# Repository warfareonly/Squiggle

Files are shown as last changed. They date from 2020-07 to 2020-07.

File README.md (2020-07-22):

This is a fork of ibnuda's Squiggle keyboard, with minor (aesthetic) changes
for myself!

# Squiggle Keyboard

It's a keyboard family which based on my circumstances, preferences, and
observed usages.

Requirements:

- 5 columns per hand.
  My right pinky is almost useless.
- At most 3 keys for each side's thumb row.
  My right thumb key is almost useless.
- No numrow.
  It's harder and more cumbersome to use than a numpad on a layer.
- Split.
  Typing on single flat keyboard hurts my arms in a lot of use cases.
- Symmetric.
  Personal preferences.

This family keyboard repo will not have any of the following features:

- OLED Screen: useless.
- LEDs: useless for me and hurt my eyes.
- Rotary Encoder: useless for me.
- Hotswap: I need a commitment.
- Case for `Low Profile`: defeating the whole purpose of ***LOW*** profile.

## Screenshot

### Standard

- MX and Alps style switches.
- 34 Keys.
- 4x2u thumb keys.
- 2 Promicros.
- TRRS/TRS cable.

standard version

### Low Profile

- Dongguan Kaihua Electronics Co., Ltd (originally named Longhua Electronics)'s
  Choc style switches.
- 34 Keys.
- 4x2u thumb keys.
- 2 Promicros.
- TRRS/TRS cable.

low profile

### 36 Keys

- MX and Alps style switches.
- 36 Keys.
- 4x2u+2x1.25u thumb keys.
- 2 Promicros.
- TRRS/TRS cable.

36 keys

### Minimalist

- MX and Alps style switches.
- 34 Keys.
- 4x2u thumb keys.
- 1 Promicros.
- "Amphenol 10 wire" cable.

minimalist

### Goldberg

(Because it's more complex than necessary. It's just a damn keyboard.)

- MX and Alps style switches.
- 34 - 38 Keys.
- 4x2u or 8x1u thumb keys. (or anything in between)
- 2 Promicros.
- TRRS/TRS cable.

goldberg

## Disclaimer

I haven't printed some of it. But, theoretically, they should just work.
Oh, if things go wrong, I won't take any responisibilities.

## Additional Note

Any files with `mokou_*.kicad_mod` in `libs/footprints` are made by [Jokan Hiyou](https://twitter.com/jokanhiyou)
and belong to hers.
I just dither them and made them kicad footprints.

## License

GPLv3.

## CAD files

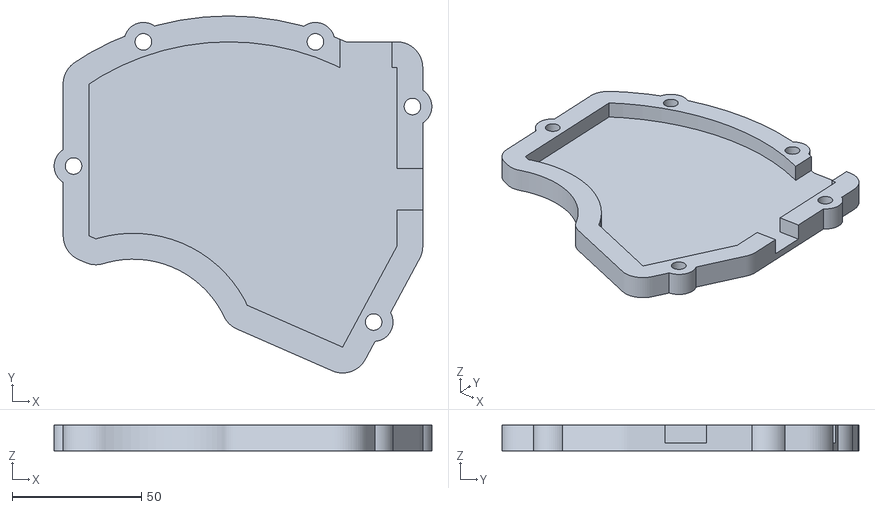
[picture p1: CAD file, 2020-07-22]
goldberg/plates/goldberg_lp_bottom_left.stl
146.0 x 138.0 x 10.0

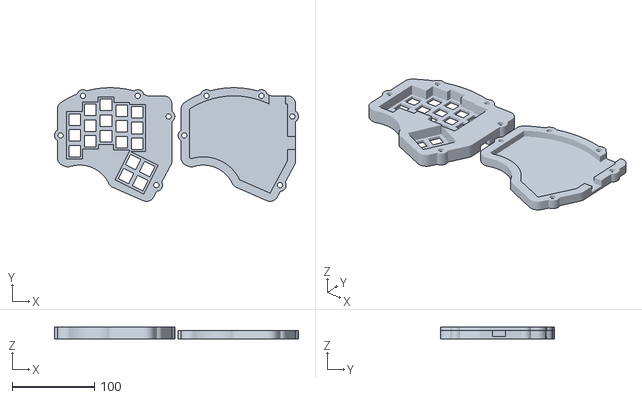
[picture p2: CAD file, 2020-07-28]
plates/another-case.stl
296.0 x 138.0 x 14.0

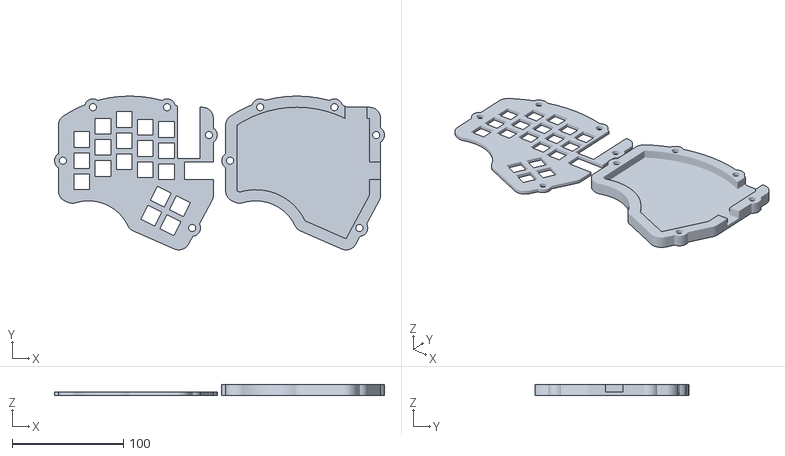
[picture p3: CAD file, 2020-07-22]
goldberg/plates/goldberg_lp.stl
296.0 x 138.0 x 10.0

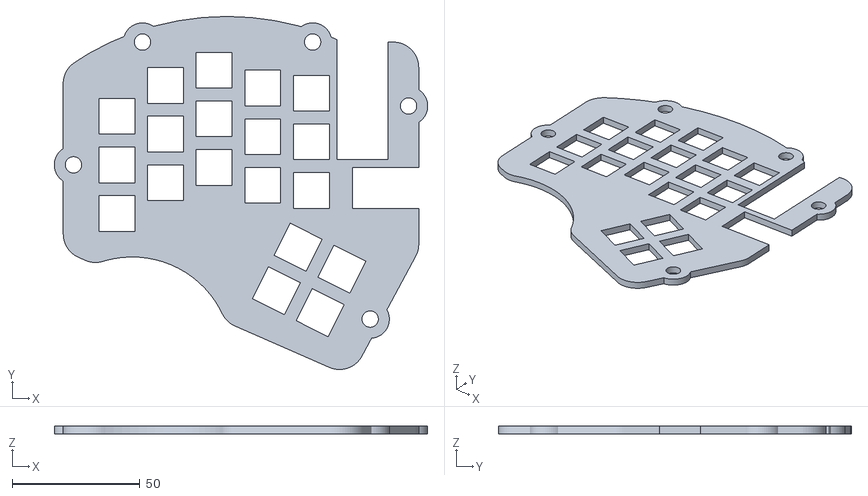
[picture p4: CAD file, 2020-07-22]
goldberg/plates/goldberg_lp_middle_top.stl
146.0 x 138.0 x 3.00

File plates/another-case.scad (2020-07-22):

include <common.scad>;

$fn = 60;

bottom_thickness = 3;
middle_thickness = 7;
switch_thickness = 3;
top_thickness = 9;

use_tenting_screws = true;

is_36 = false;

is_case = true;

is_goldberg = true;

is_high = false;

module
bottom_plate()
{
    difference()
    {
        union()
        {
            offset(r = 10) shape_of_pcb();
            if (use_tenting_screws) {
                for (i = [0:len(tenting_screw_positions) - 1]) {
                    translate(tenting_screw_positions[i]) tenting_wing();
                }
            }
        }
        if (use_tenting_screws) {
            for (i = [0:len(tenting_screw_positions) - 1]) {
                translate(tenting_screw_positions[i]) tenting_hole();
            }
        } else {
            for (i = [0:len(tightening_screw_positions) - 1]) {
                translate(tightening_screw_positions[i]) tightening_hole();
            }
        }
    }
}

module
middle_plate()
{
    difference()
    {
        bottom_plate();
        shape_of_pcb();
        promicro_trrs_space();
    }
}

module upper_plate(hole_width, is_switch_plate = true)
{
    difference()
    {
        bottom_plate();
        alpha_holes(hole_width);
        thumb_hole(96.6, -98.7, 153.4, is_switch_plate, hole_width, is_goldberg);
        thumb_hole(113.7, -107.3, -26.6, is_switch_plate, hole_width, is_goldberg);
        if (is_switch_plate)
        {
            promicro_trrs_space();
        }
        if (is_36)
        {
            inner_thumb_hole(hole_width);
        }
    }
}

if (is_case) {
    translate([ 150, 0, 0 ]) color([ 0.4, 0.3, 0.2 ])
    {
        linear_extrude(height = bottom_thickness) { bottom_plate(); }
    }
    translate([ 150, 0, bottom_thickness ]) color([ 0.2, 0.3, 0.2 ])
    {
        linear_extrude(height = middle_thickness) { middle_plate(); }
    }
    translate([ 0, 0, 0 ]) color([ 0.3, 0.3, 0.3 ])
    {
        linear_extrude(height = switch_thickness) { upper_plate(14, true); }
    }
    if (is_high) {
        difference()
        {
            translate([ 0, 0, switch_thickness ]) color([ 0.5, 0.5, 0.5 ])
            {
                linear_extrude(height = top_thickness)
                {
                    upper_plate(19.5, false);
                }
            }
            translate([ 0, 0, switch_thickness ]) linear_extrude(height = 3)
            {
                promicro_trrs_space();
            }
        }
    }
} else {
    translate([ 140, 0, 3 ]) color([ 0.2, 0.2, 0.2 ]) bottom_plate();
    translate([ 0, 140, 3 ]) color([ 0.2, 0.2, 0.2 ]) middle_plate();
    translate([ 0, 0, 6 ]) color([ 0.2, 0.2, 0.9 ]) upper_plate(14, true);
}

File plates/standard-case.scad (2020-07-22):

$fn = 60;

bottom_thickness = 3;
middle_thickness = 7;
switch_thickness = 3;
top_thickness = 7;

is_36 = false;

is_case = true;

is_goldberg = true;

is_high = true;

module sector(radius, angles, fn = 60)
{
    r = radius / cos(180 / fn);
    step = -360 / fn;

    points = concat(
        [[ 0, 0 ]],
        [for (a = [angles[0]:step:angles[1] - 360])[r * cos(a), r * sin(a)]],
        [[r * cos(angles[1]), r * sin(angles[1])]]);

    difference()
    {
        circle(radius, $fn = fn);
        polygon(points);
    }
}

module arc(radius, angles, width = 1, fn = 60)
{
    difference()
    {
        sector(radius + width, angles, fn);
        sector(radius, angles, fn);
    }
}

module
single_screw_hole()
{
    circle(r = 1.2);
}

module
screw_holes()
{
    union()
    {
        translate([ 17.5, -26, 0 ]) single_screw_hole();
        translate([ 18.5, -88, 0 ]) single_screw_hole();
        translate([ 81.0, -116, 0 ]) single_screw_hole();
        translate([ 118.5, -132.5, 0 ]) single_screw_hole();
        translate([ 139, -88.5, 0 ]) single_screw_hole();
        translate([ 140, -56.5, 0 ]) single_screw_hole();
        translate([ 140, -20.5, 0 ]) single_screw_hole();
        translate([ 112.5, -17.2, 0 ]) single_screw_hole();
        translate([ 71, -8.6, 0 ]) single_screw_hole();
    }
}

tenting_positions =
    [ [ 129, -118.3 ], [ 40, -10 ], [ 106.5, -11.5 ], [ 13, -58 ], [ 145, -35 ] ];

module
tenting_wing()
{
    circle(r = 6.4);
}

module
tenting_hole()
{
    circle(r = 3.2);
}

module
promicro_trrs_space()
{
    union()
    {
        // promicro space.
        polygon(points = [
            [ 116, -12 ],
            [ 136, -12 ],
            [ 136, -56 ],
            [ 116, -56 ],
        ]);
        // trrs jack space.
        polygon(points = [
            [ 148, -75 ],
            [ 148, -59 ],
            [ 122, -59 ],
            [ 122, -75 ],
        ]);
    }
}

module
alpha_holes()
{
    for (j = [0:2]) {
        translate([ 0, (j * 19), 0 ])
        {
            for (i = [0:4]) {
                translate([ (i * 19), 0, 0 ])
                {
                    square(size = [ 14, 14 ], center = true);
                }
            }
        }
    }
}

module lone_hole(width = 14)
{
    translate([ 79.57, -90.06 ])
    {
        rotate([ 0, 0, 63.4 ])
        {
            square(size = [ width, width ], center = true);
        }
    }
}

stagger = [ -39, -27, -21, -28, -30 ];

module alpha_holes(width = 14)
{
    for (i = [0:2]) {
        for (j = [0:4]) {
            translate([ (30 + j * 19), (stagger[j] - i * 19) ])
                square(size = [ width, width ], center = true);
        }
    }
}

module
inner_room()
{
    angles = [ 63.7, 123.5 ];
    anglea = [ 15, 112 ];
    difference()
    {
        union()
        {
            translate([ 73, -108 ]) sector(98, angles, 72);
            polygon(points = [
                [ 19, -26.4 ],
                [ 19, -85 ],
                [ 117, -128 ],
                [ 138, -89 ],
                [ 138, -20 ],
                [ 116, -20 ],
            ]);
        }
        translate([ 36, -133 ]) sector(49, anglea, 75);
    }
}

module
bottom_plate()
{
    angle_upper = [ 63.7, 125.6 ];
    angle_lower = [ 15, 122 ];
    difference()
    {
        union()
        {
            translate([ 73, -108 ]) sector(105, angle_upper, 72);
            polygon(points = [
                [ 12, -22.8 ],
                [ 12, -89 ],
                [ 118.5, -141.5 ],
                [ 146, -89 ],
                [ 146, -14 ],
                [ 116, -14 ],
            ]);
            for (i = [0:len(tenting_positions) - 1]) {
                translate(tenting_positions[i]) tenting_wing();
            }
        }
        translate([ 36, -133 ]) sector(41.5, angle_lower, 75);
        // screw_holes();
        for (i = [0:len(tenting_positions) - 1]) {
            translate(tenting_positions[i]) tenting_hole();
        }
    }
}

module
thumb_imported_from_file()
{
    translate([ 7, -6.3, 0 ])
    {
        rotate([ 0, 0, -30 ]) { import("2u-cutout.dxf"); }
    }
}

module
thumb_two_u()
{
    union()
    {
        translate([ 0, 9.5, 0 ]) { square(size = [ 14, 14 ], center = true); }
        translate([ 0, -9.5, 0 ]) { square(size = [ 14, 14 ], center = true); }
    }
}
module upper_plate(hole_width, is_switch_plate = false)
{
    difference()
    {
        bottom_plate();
        translate([ 96.6, -98.7, 0 ])
        {
            rotate([ 0, 0, 153.4 ])
            {
                if (is_switch_plate) {
                    if (is_goldberg) {
                        thumb_two_u();
                    } else {
                        thumb_imported_from_file();
                    }
                } else {
                    square(size = [ hole_width, hole_width * 2 ],
                           center = true);
                };
            }
        }
        translate([ 113.7, -107.3, 0 ])
        {
            rotate([ 0, 0, -26.6 ])
            {
                if (is_switch_plate) {
                    if (is_goldberg) {
                        thumb_two_u();
                    } else {
                        thumb_imported_from_file();
                    }
                } else {
                    square(size = [ hole_width, hole_width * 2 ],
                           center = true);
                };
            }
        }
        alpha_holes(hole_width);
        if (is_36) {
            lone_hole(hole_width);
        }
        if (is_switch_plate) {
            promicro_trrs_space();
        }
    }
}

module
middle_plate()
{
    difference()
    {
        bottom_plate();
        inner_room();
        promicro_trrs_space();
    }
}

if (is_case) {
    translate([ 150, 0, 0 ]) color([ 0.4, 0.3, 0.2 ])
    {
        linear_extrude(height = bottom_thickness) { bottom_plate(); }
    }
    translate([ 150, 0, bottom_thickness ]) color([ 0.2, 0.3, 0.2 ])
    {
        linear_extrude(height = middle_thickness) { middle_plate(); }
    }
    translate([ 0, 0, 0 ]) color([ 0.3, 0.3, 0.3 ])
    {
        linear_extrude(height = switch_thickness) { upper_plate(14, true); }
    }
    if (is_high) {
        difference()
        {
            translate([ 0, 0, switch_thickness ]) color([ 0.5, 0.5, 0.5 ])
            {
                linear_extrude(height = top_thickness)
                {
                    upper_plate(19.5, false);
                }
            }
            translate([ 0, 0, switch_thickness ]) linear_extrude(height = 3)
            {
                promicro_trrs_space();
            }
        }
    }
} else {
    translate([ 140, 0, 3 ]) color([ 0.2, 0.2, 0.2 ]) bottom_plate();
    translate([ 0, 140, 3 ]) color([ 0.2, 0.2, 0.2 ]) middle_plate();
    translate([ 0, 0, 6 ]) color([ 0.2, 0.2, 0.9 ]) upper_plate(14, true);
}

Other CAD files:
goldberg/plates/goldberg_lp_bottom_right.stl

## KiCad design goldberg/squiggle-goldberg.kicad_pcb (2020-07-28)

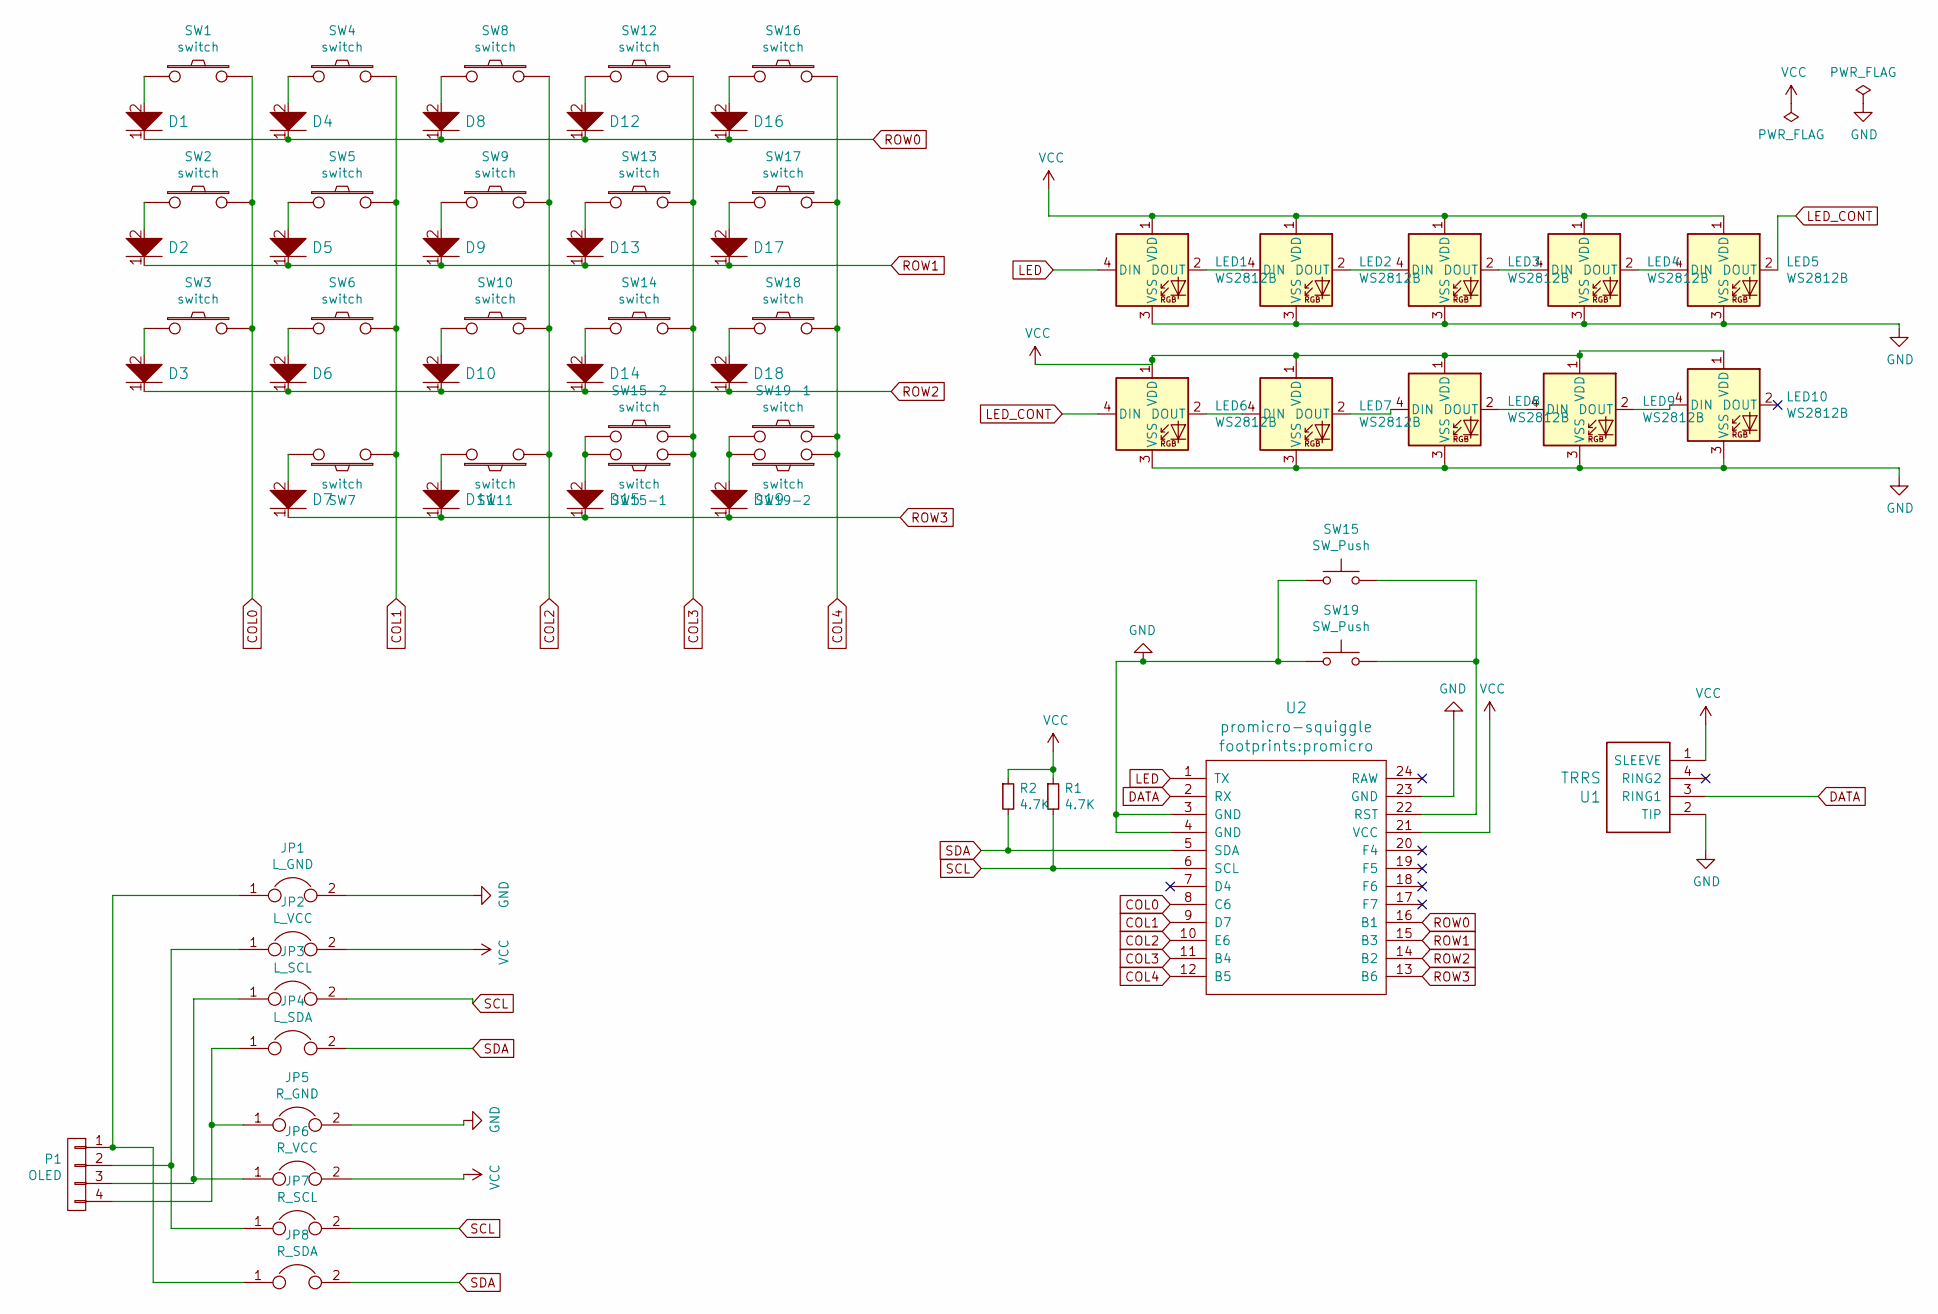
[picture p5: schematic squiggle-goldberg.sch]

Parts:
D1, D2, D3, D4, D5, D6, D7, D8, D9, D10, D11, D12, D13, D14, D15, D16, D17, D18, D19: D; diode
JP1: L_GND; Jumper
JP2: L_VCC; Jumper
JP3: L_SCL; Jumper
JP4: L_SDA; Jumper
JP5: R_GND; Jumper
JP6: R_VCC; Jumper
JP7: R_SCL; Jumper
JP8: R_SDA; Jumper
LED1, LED2, LED3, LED4, LED5, LED6, LED7, LED8, LED9, LED10: WS2812B; LED_WS2812B_4Pad
P1: OLED; SSD_1306_128x32
R1, R2: 4.7K; R_Axial_DIN0207_L6.3mm_D2.5mm_P10.16mm_Horizontal
SW1, SW2, SW3, SW4, SW5, SW6, SW7, SW8, SW9, SW10, SW11, SW12, SW13, SW14, SW15-2, SW16, SW17, SW18, SW19-2: switch; 1u-dual
SW15, SW19: SW_Push; SW_PUSH_6mm_H5mm
SW15-1, SW19-1: switch; 2u-dual
U1: TRRS; trrs
U2: promicro-squiggle; promicro

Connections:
COL0: SW1.2, SW2.2, SW3.2, U2.8 (C6)
COL1: SW4.2, SW5.2, SW6.2, SW7.1, U2.9 (D7)
COL2: SW8.2, SW9.2, SW10.2, SW11.1, U2.10 (E6)
COL3: SW12.2, SW13.2, SW14.2, SW15-1.1, SW15-2.2, U2.11 (B4)
COL4: SW16.2, SW17.2, SW18.2, SW19-1.2, SW19-2.1, U2.12 (B5)
DATA: U1.3 (RING1), U2.2 (RX)
GND: JP1.2, JP5.2, LED1.3 (VSS), LED2.3 (VSS), LED3.3 (VSS), LED4.3 (VSS), LED5.3 (VSS), LED6.3 (VSS), LED7.3 (VSS), LED8.3 (VSS), LED9.3 (VSS), LED10.3 (VSS), SW15.1, SW19.1, U1.2 (TIP), U2.3 (GND), U2.4 (GND), U2.23 (GND)
LED: LED1.4 (DIN), U2.1 (TX)
LED_CONT: LED5.2 (DOUT), LED6.4 (DIN)
unnamed: D1.2, SW1.1
unnamed: D2.2, SW2.1
unnamed: D3.2, SW3.1
unnamed: D4.2, SW4.1
unnamed: D5.2, SW5.1
unnamed: D6.2, SW6.1
unnamed: D7.2, SW7.2
unnamed: D8.2, SW8.1
unnamed: D9.2, SW9.1
unnamed: D10.2, SW10.1
unnamed: D11.2, SW11.2
unnamed: D12.2, SW12.1
unnamed: D13.2, SW13.1
unnamed: D14.2, SW14.1
unnamed: D15.2, SW15-1.2, SW15-2.1
unnamed: D16.2, SW16.1
unnamed: D17.2, SW17.1
unnamed: D18.2, SW18.1
unnamed: D19.2, SW19-1.1, SW19-2.2
unnamed: JP1.1, JP8.1, P1.1
unnamed: JP2.1, JP7.1, P1.2
unnamed: JP3.1, JP6.1, P1.3
unnamed: JP4.1, JP5.1, P1.4
unnamed: LED1.2 (DOUT), LED2.4 (DIN)
unnamed: LED2.2 (DOUT), LED3.4 (DIN)
unnamed: LED3.2 (DOUT), LED4.4 (DIN)
unnamed: LED4.2 (DOUT), LED5.4 (DIN)
unnamed: LED6.2 (DOUT), LED7.4 (DIN)
unnamed: LED7.2 (DOUT), LED8.4 (DIN)
unnamed: LED8.2 (DOUT), LED9.4 (DIN)
unnamed: LED9.2 (DOUT), LED10.4 (DIN)
unnamed: SW15.2, SW19.2, U2.22 (RST)
ROW0: D1.1, D4.1, D8.1, D12.1, D16.1, U2.16 (B1)
ROW1: D2.1, D5.1, D9.1, D13.1, D17.1, U2.15 (B3)
ROW2: D3.1, D6.1, D10.1, D14.1, D18.1, U2.14 (B2)
ROW3: D7.1, D11.1, D15.1, D19.1, U2.13 (B6)
SCL: JP3.2, JP7.2, R1.2, U2.6 (SCL)
SDA: JP4.2, JP8.2, R2.2, U2.5 (SDA)
VCC: JP2.2, JP6.2, LED1.1 (VDD), LED2.1 (VDD), LED3.1 (VDD), LED4.1 (VDD), LED5.1 (VDD), LED6.1 (VDD), LED7.1 (VDD), LED8.1 (VDD), LED9.1 (VDD), LED10.1 (VDD), R1.1, R2.1, U1.1 (SLEEVE), U2.21 (VCC)

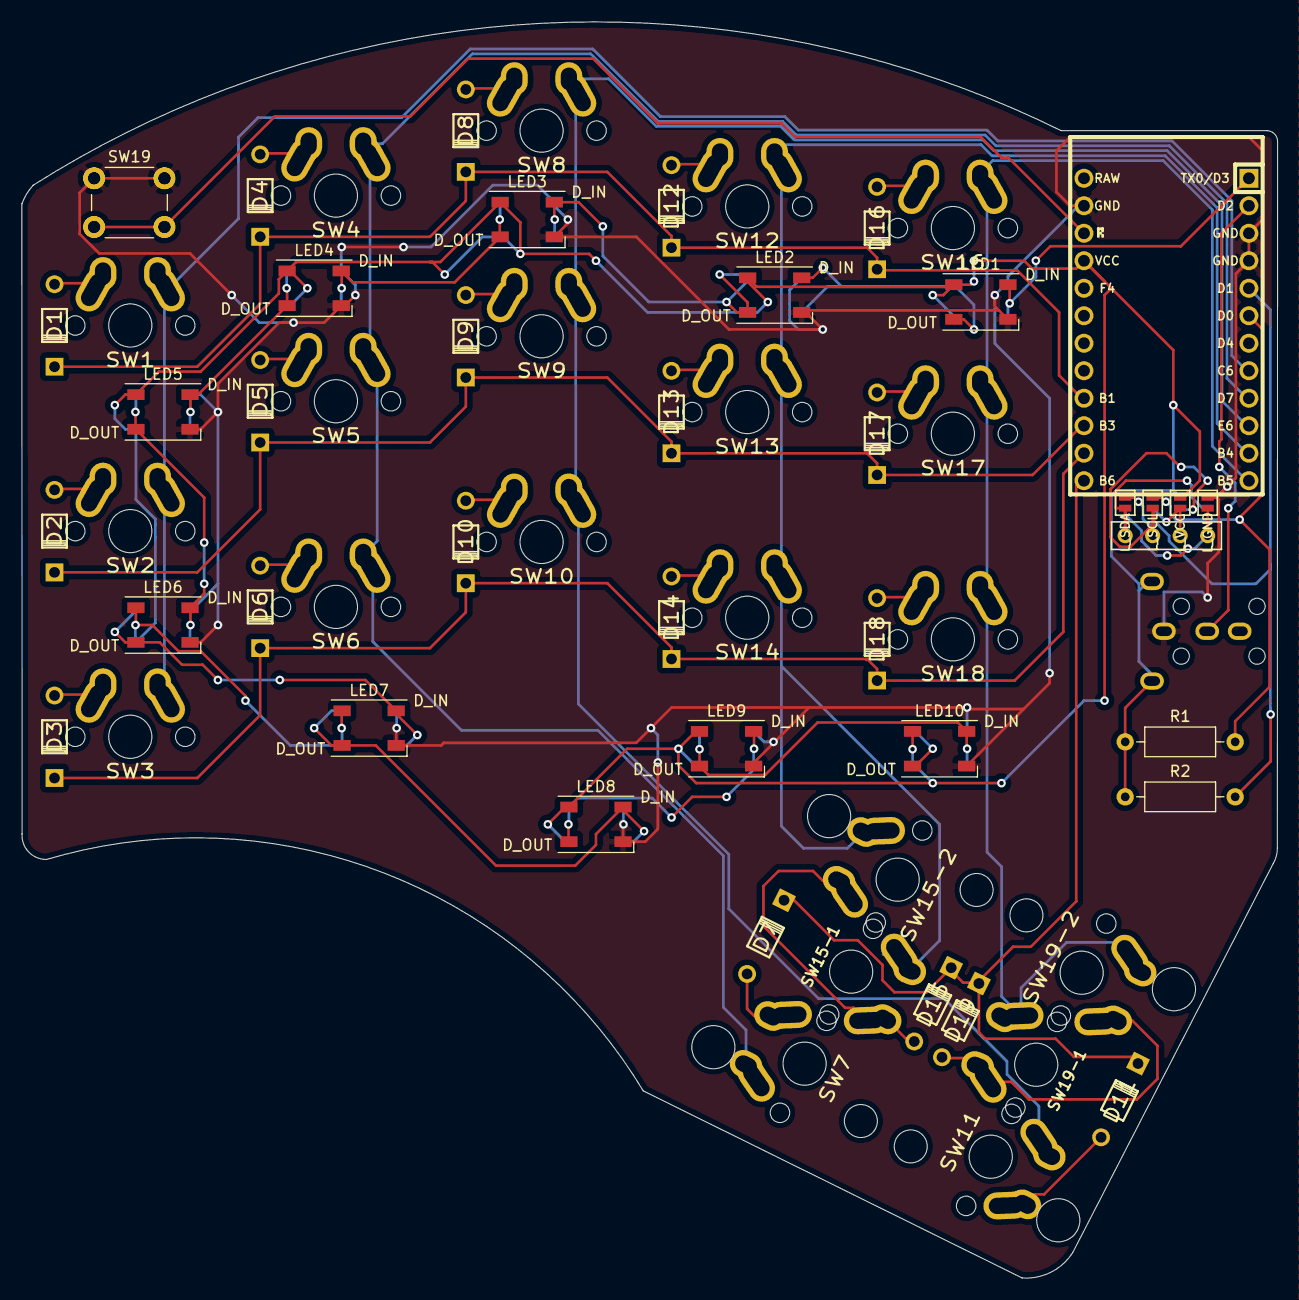
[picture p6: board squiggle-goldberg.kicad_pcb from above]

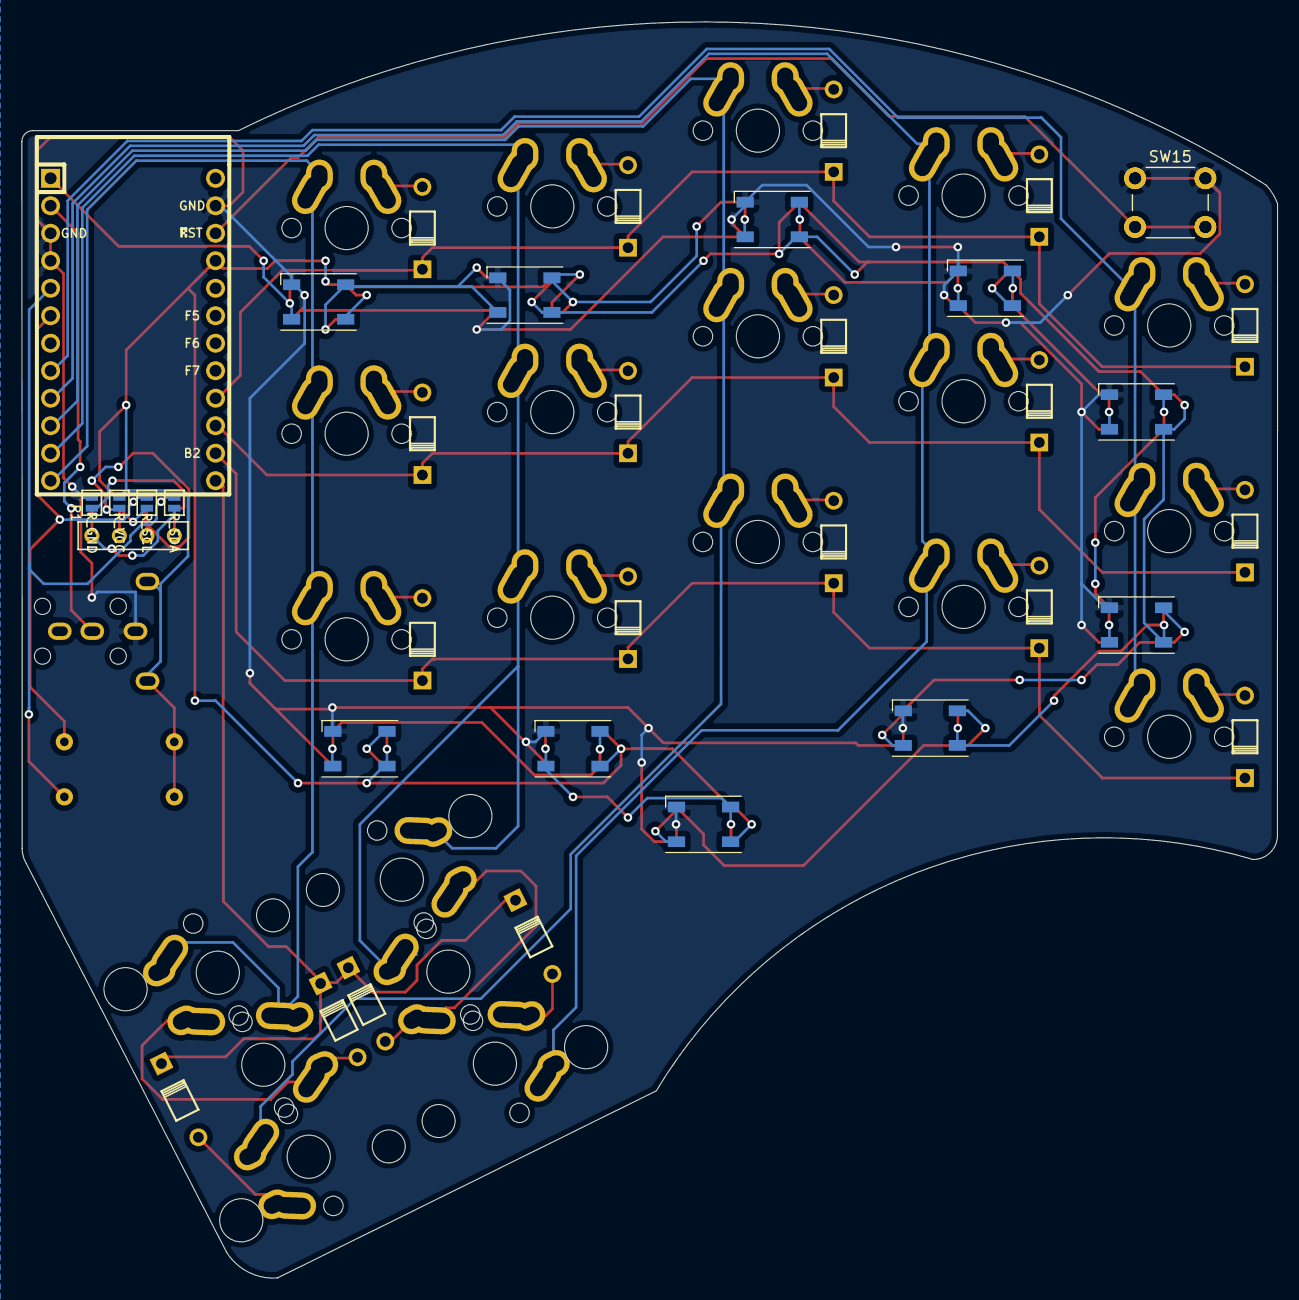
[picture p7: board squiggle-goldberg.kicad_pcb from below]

Board: 2 copper layers, 116.0 x 116.1 mm, 65 parts (8 on the bottom side), 48 nets.

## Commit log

2020-07-22 Modified the goldberg design files for myself
    [another-case.scad, squiggle-goldberg.kicad_pcb, standard-case.scad]
2020-07-22 Goldberg LP settings
    [another-case.scad]
2020-07-22 Updated the Goldberg PCB with correct memes
    [squiggle-goldberg.kicad_pcb]
2020-07-22 Goldberg LP STLs
    [goldberg_lp.stl, goldberg_lp_bottom_left.stl, goldberg_lp_bottom_right.stl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]
2020-07-24 Initial efforts towards adding I2C and LEDs
    [squiggle-goldberg.kicad_pcb, squiggle-goldberg.sch]
2020-07-27 Added footprints from ergoslab
2020-07-27 Added OLED
    [squiggle-goldberg.kicad_pcb, squiggle-goldberg.sch]
2020-07-27 Added 128x64 OLED footprint and LED footprint
2020-07-27 Updated PCB
    [squiggle-goldberg.kicad_pcb]
2020-07-27 PC change
    [base.kicad_pcb, middle.kicad_pcb, squiggle-goldberg.sch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]
2020-07-27 Added LEDs and RESET button
    [squiggle-goldberg.kicad_pcb, squiggle-goldberg.sch]
2020-07-28 Added GND fill to both Cu layers
    [squiggle-goldberg.kicad_pcb]
